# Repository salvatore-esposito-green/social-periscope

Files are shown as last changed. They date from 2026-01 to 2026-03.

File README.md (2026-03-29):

🛰️ ESP32 Social Periscope (Radar Badge)
========================================

### 🔗 Project Context & Evolution

This experiment is based on the **[Codemotion Smart Badge](https://github.com/Codemotion-Official/CMNode)**. It was born from the idea of hacking and developing custom add-ons for the **CMNode V0** version.

While the original project was designed for **passive operation** (displaying check-in data), this "Social Periscope" version evolves the hardware into an **active device** capable of real-time peer-to-peer detection and interaction.

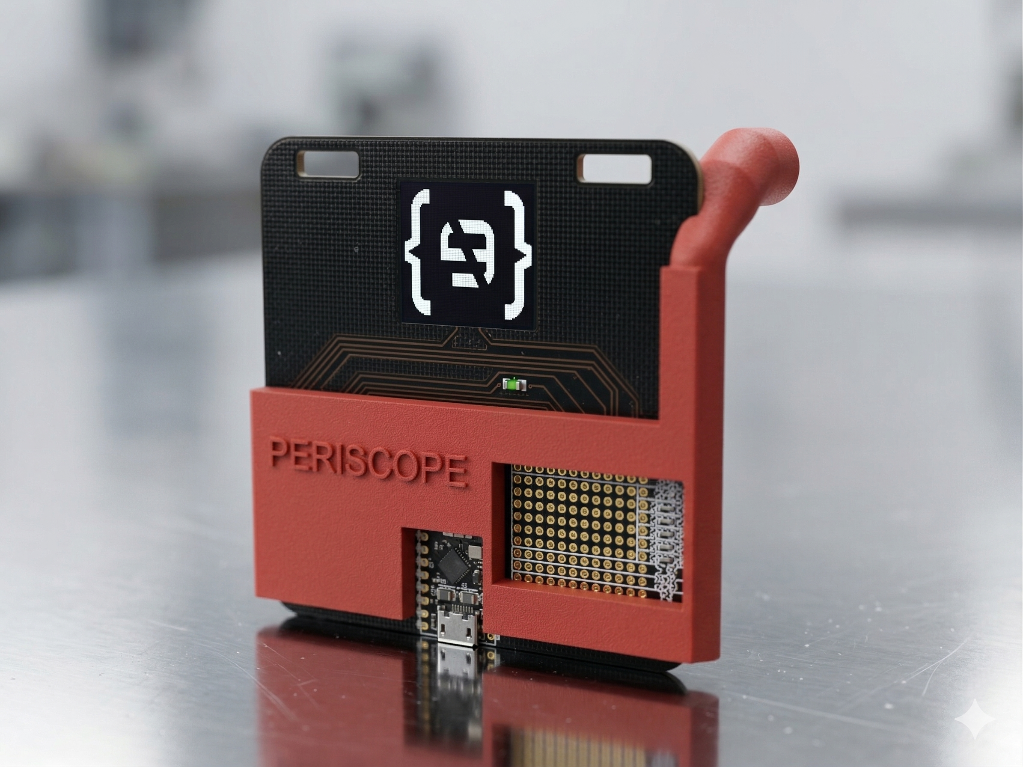
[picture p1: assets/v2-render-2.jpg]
Codemotion Badge Original


## Overview: The "Active" Evolution

This firmware transforms the static badge into an interactive **Social Radar**. It uses **ESP-NOW** and **RSSI (Signal Strength)** monitoring to detect other nearby badges, automatically swapping contact information when you get close to another attendee.

Badge Demo
📹 **[Watch full demo video on YouTube](https://youtu.be/3y3iBChB-LI)**

### Key Logic Overview

1.  **Broadcast**: Every 300ms, the device sends its own profile data to any nearby device.
2.  **Detection (Proximity Alert)**: It calculates a "Smooth RSSI" (signal strength). As a peer gets closer, the buzzer beeps faster and at a higher pitch (Geiger-counter style).
3.  **Target Acquisition**: If a peer is very close (RSSI > -80), it triggers a 5-second alarm and then updates the E-Paper display with the "Target's" information and QR code.

### 🚀 How It Works

1.  **Broadcast Mode**: The device constantly broadcasts your profile (Name, Role, Company, and QR Link) via **ESP-NOW** (no Wi-Fi router required).
2.  **Proximity Sensing**: It monitors the **RSSI** (Signal Strength) of nearby devices.
3.  **Geiger-Style Alerts**: As you get closer to another user, the buzzer beeps faster and at a higher pitch.
4.  **Target Acquisition**: If someone stays within immediate range (approx. 1-2 meters) for a few seconds, the device "locks on," triggers an alarm, and updates the E-Paper display with the other person's details and QR code.

### 🛠 Hardware Configuration

This version assumes the following components are added to the base CMNode V0:

*   **Microcontroller**: ESP32 (e.g., ESP32-S3 or C3)
*   **Display**: GxEPD2 compatible 2.9" 3-Color E-Paper Display
*   **Audio**: Active/Passive Buzzer (connected to Pin 3)
*   **Visual**: Status LED (connected to Pin 8)
*   **Communication**: ESP-NOW (2.4GHz)

### 🏗️ Physical Build & Assembly

#### v2 — Improved Design

> An updated version of the enclosure with a revised CAD model, optimized for better component fit and aesthetics.

<table>
  <tr>
    <td width="50%">
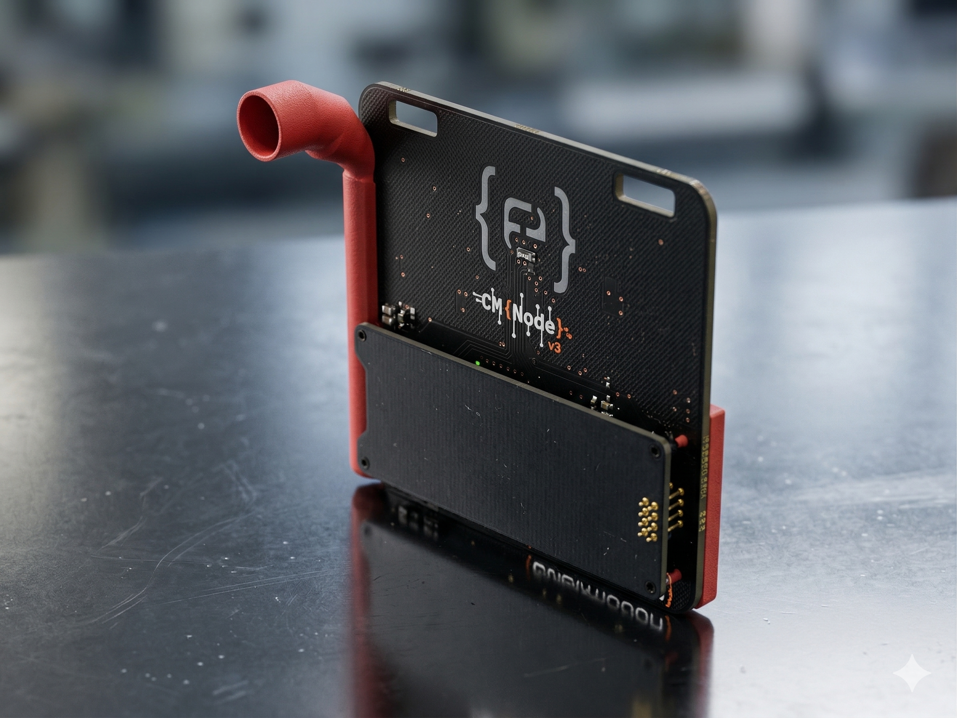
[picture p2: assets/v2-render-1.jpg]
v2 Render 1
      
      <p align="center"><em>Photorealistic render — front</em></p>
    </td>
    <td width="50%">
      v2 Render 2
      <p align="center"><em>Photorealistic render — back</em></p>
    </td>
  </tr>
</table>

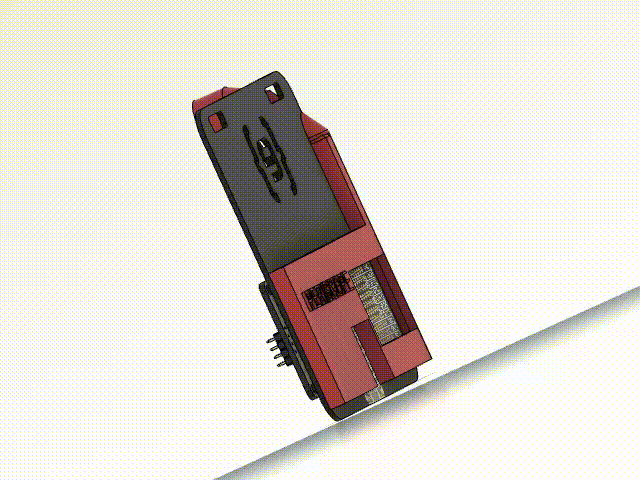
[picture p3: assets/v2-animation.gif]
v2 3D Animation


<table>
  <tr>
    <td width="50%">
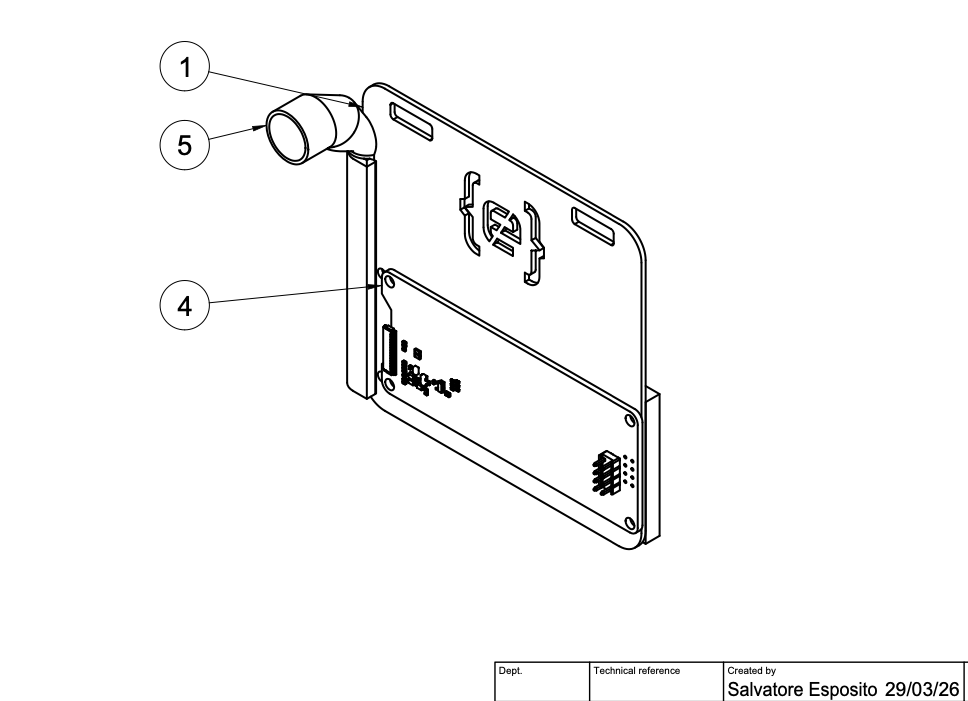
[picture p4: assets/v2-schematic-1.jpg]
Design schematic 1
      
      <p align="center"><em>Design schematic — sheet 1</em></p>
    </td>
    <td width="50%">
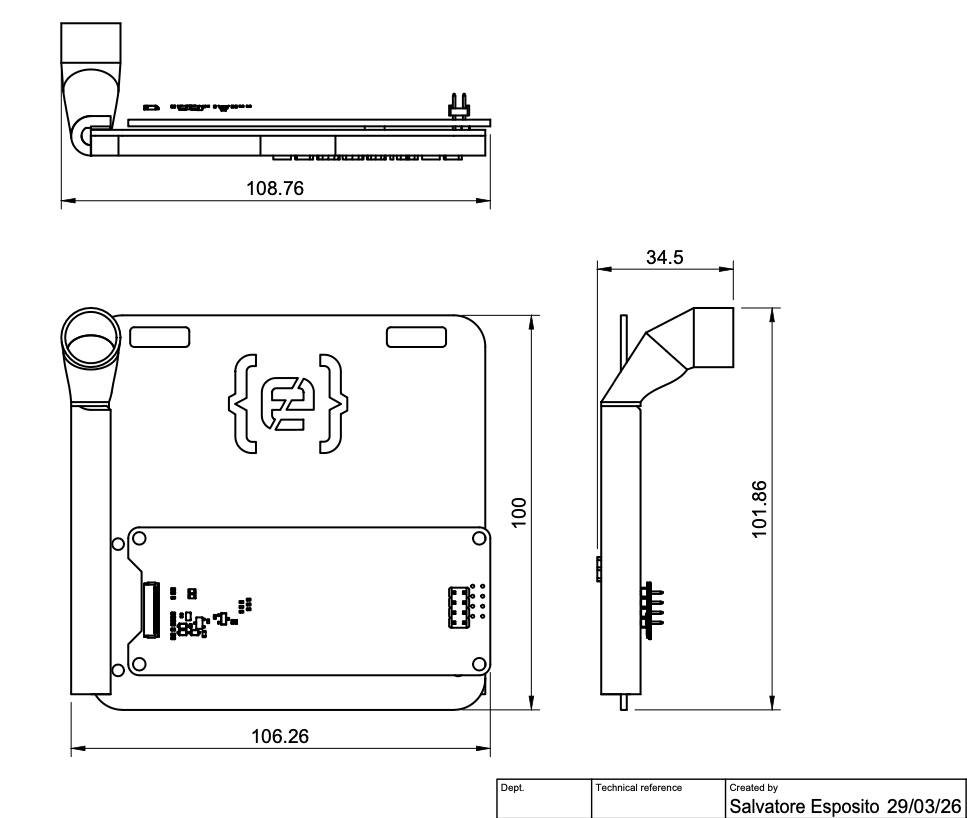
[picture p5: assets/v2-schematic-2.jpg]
Design schematic 2
      
      <p align="center"><em>Design schematic — sheet 2</em></p>
    </td>
  </tr>
</table>

<table>
  <tr>
    <td width="50%">
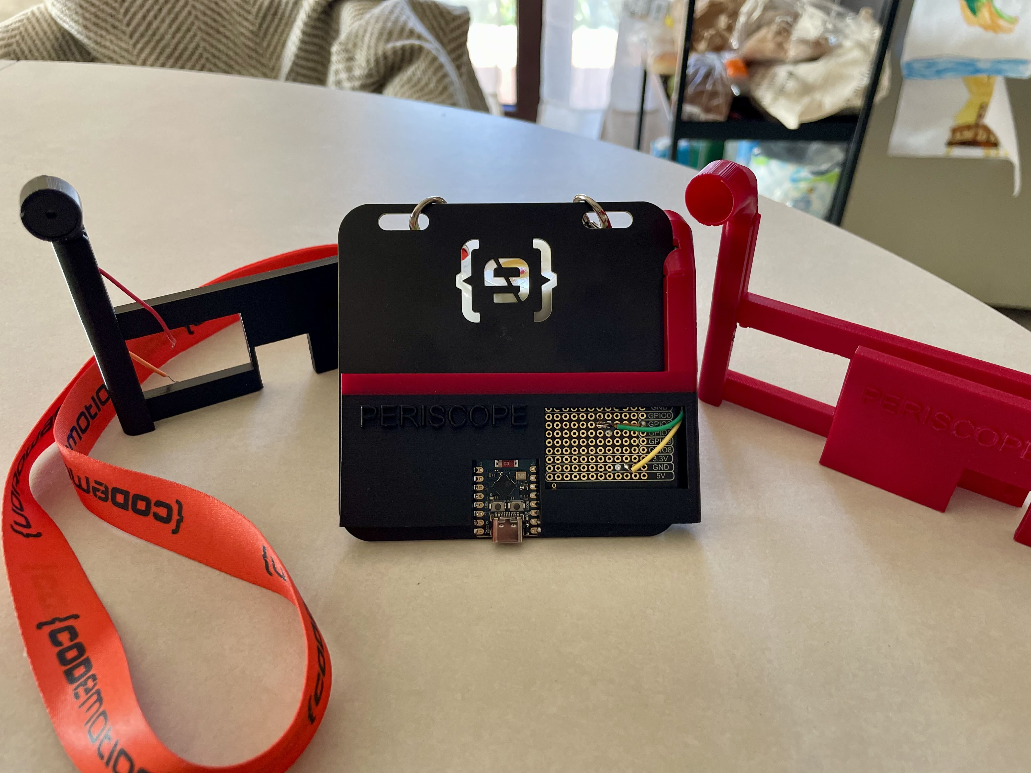
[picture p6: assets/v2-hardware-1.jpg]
v2 hardware on table 1
      
      <p align="center"><em>Badge and supports — table view</em></p>
    </td>
    <td width="50%">
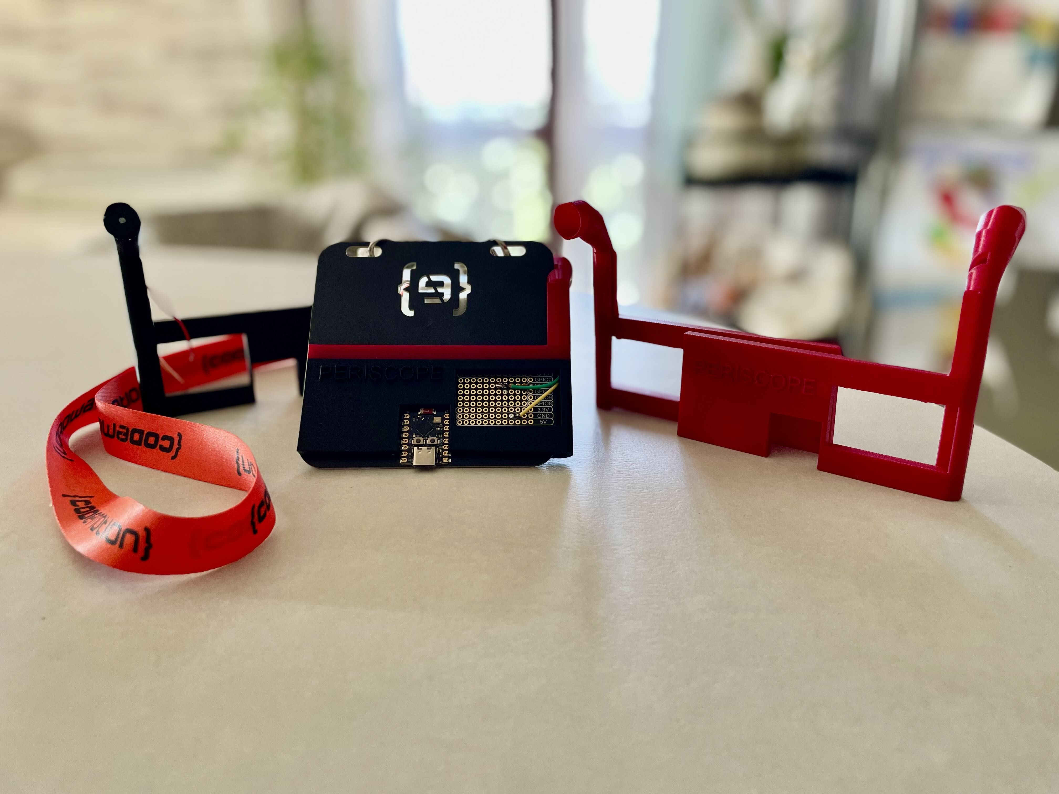
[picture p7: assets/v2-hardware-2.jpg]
v2 hardware on table 2
      
      <p align="center"><em>Badge and supports — table view</em></p>
    </td>
  </tr>
</table>

📦 **[Download STL file](assets/social-periscope-v2.stl)**

---

#### v1 — Original Build

> The first physical iteration, built and tested at the Codemotion event.

<table>
  <tr>
    <td width="50%">
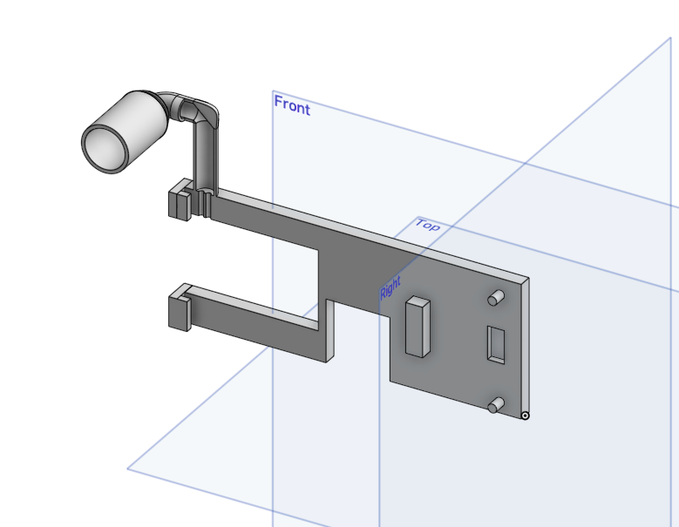
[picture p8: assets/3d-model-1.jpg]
      
      <p align="center"><em>3D modeling of the periscope</em></p>
    </td>
    <td width="50%">
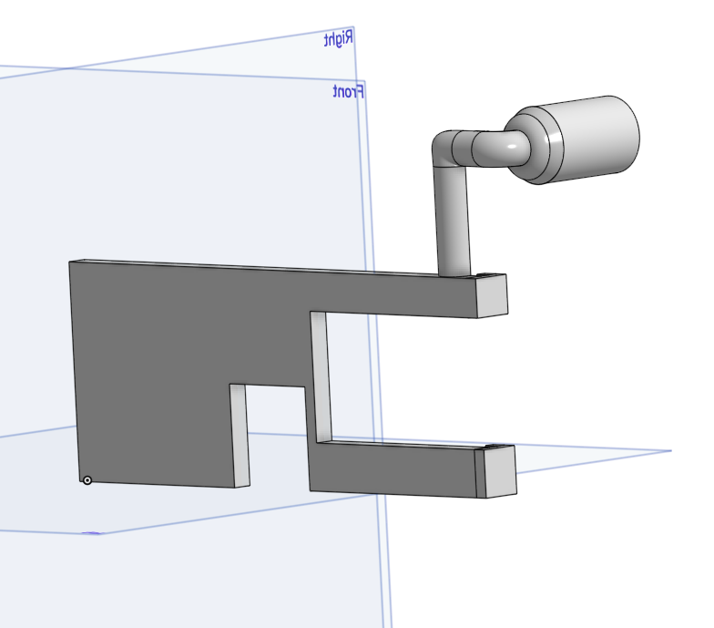
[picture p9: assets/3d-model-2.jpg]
      
      <p align="center"><em>3D modeling of the periscope</em></p>
    </td>
  </tr>
    <tr>
    <td width="50%">
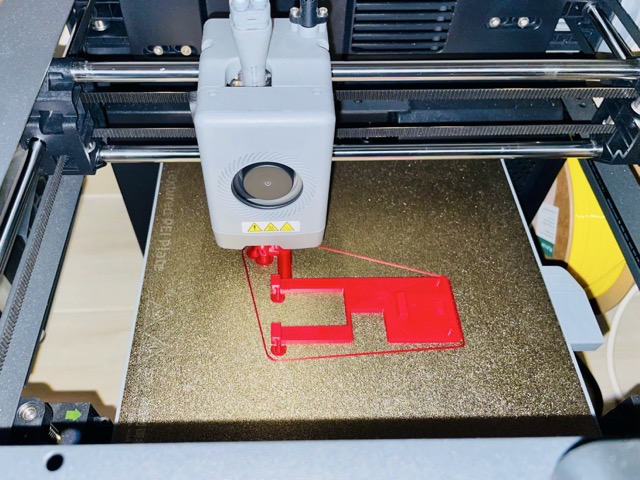
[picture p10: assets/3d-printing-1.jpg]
3D Printing in Progress
      
      <p align="center"><em>3D printing of the case</em></p>
    </td>
    <td width="50%">
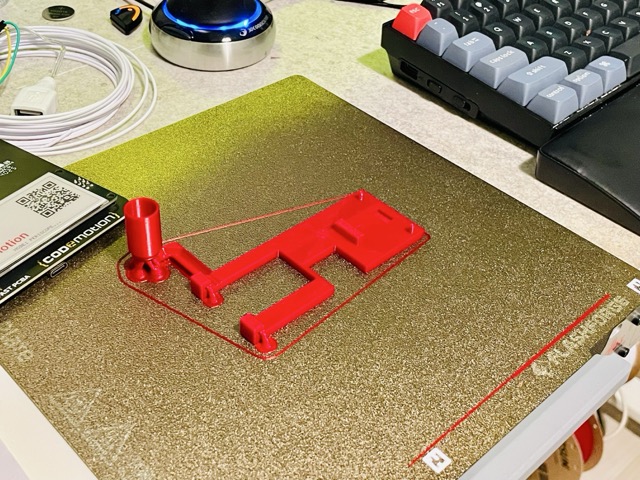
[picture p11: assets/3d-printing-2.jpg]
3D Printing in Progress
      
      <p align="center"><em>3D printing of the case</em></p>
    </td>
  </tr>
  <tr>
    <td width="50%">
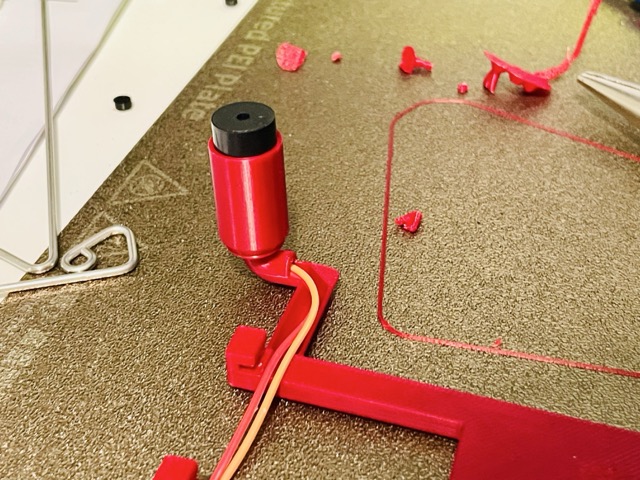
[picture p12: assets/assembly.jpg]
Buzzer Wiring
      
      <p align="center"><em>Buzzer wiring</em></p>
    </td>
    <td width="50%">
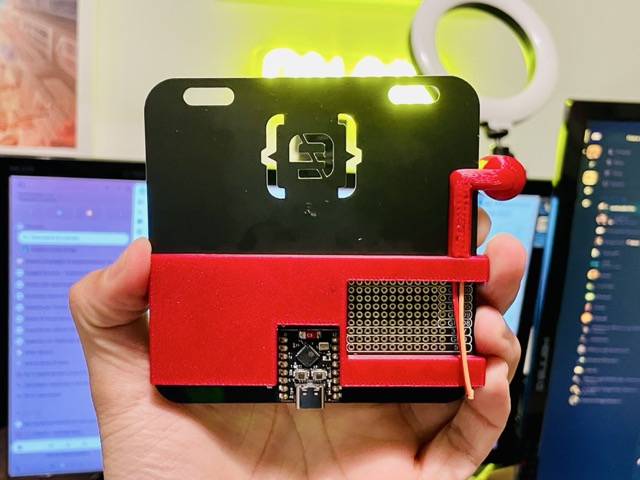
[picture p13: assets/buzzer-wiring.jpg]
Component Assembly
      
      <p align="center"><em>Assembly</em></p>
    </td>
  </tr>
  <tr>
    <td width="50%">
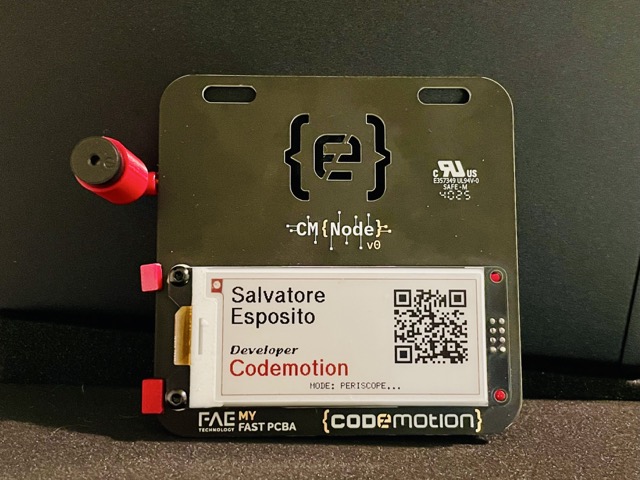
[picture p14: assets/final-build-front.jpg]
Fully Assembled Badge Front
      
      <p align="center"><em>Fully assembled badge</em></p>
    </td>
    <td width="50%">
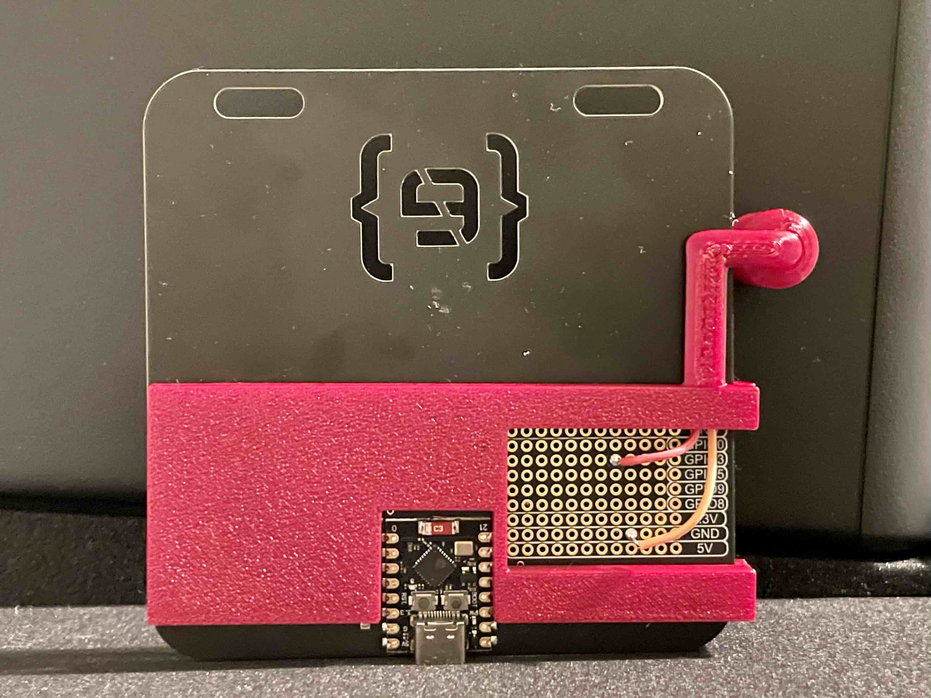
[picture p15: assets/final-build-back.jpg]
Fully Assembled Badge Back
      
      <p align="center"><em>Fully assembled badge</em></p>
    </td>
  </tr>
</table>

### 📂 Project Structure

*   **ESP-NOW Logic**: Peer-to-peer data exchange without latency.
*   **EMA Filtering**: Smooths RSSI fluctuations to prevent false "Target Acquired" triggers.
*   **Display Management**: Full refresh cycles using `GxEPD2`, featuring hibernation to preserve the E-Ink panel.
*   **Audio PWM**: Dynamic pitch mapping (800Hz to 3500Hz) based on proximity.

### 🔧 Installation & Setup

1.  **Clone the repository**:

```bash
git clone https://github.com/salvatore-esposito-green/social-periscope.git
```

2.  **Configure your Profile**: Edit the `myProfile` struct in the code:

```C++
struct_message myProfile = {"Name", "Surname", "Role", "Company", "URL"};
```

3.  **Library Dependencies**:

*   `GxEPD2`
*   `U8g2_for_Adafruit_GFX`
*   `QRCodeGFX`

4.  **Upload**: Flash to your ESP32-C3 using the Arduino IDE or PlatformIO.

### 📟 Device States

| Mode | Description | Audio/Visual Feedback |
| :--- | :--- | :--- |
| **Idle (Periscope)** | No peers detected in range. | Silent. LED is OFF. Displays **Your** profile. |
| **Detection** | Peer detected nearby (-95 to -81 dBm). | "Geiger" clicks: faster and higher pitch as the person gets closer. |
| **Locked On** | Peer within immediate range (> -80 dBm). | 5-second continuous alarm. Display updates to show **Remote User's** info. |
| **Timeout** | Peer moves away for > 2.5s. | System resets. Display returns to **Your** profile. |

### 🤝 Credits & Acknowledgments

*   **Original Project**: [Codemotion Official Smart Badge](https://github.com/Codemotion-Official/CMNode)
*   **Concept**: Hacking the CMNode V0 to explore social interactions at tech conferences.

### ⚠️ Important Notes

*   **E-Ink Refresh**: E-Paper displays take ~2-5 seconds to refresh. During this time, the device UI will be unresponsive.
*   **Power Consumption**: The device uses high-power Wi-Fi transmission for maximum range. Consider using a LiPo battery with at least 500mAh.
*   **Safety**: Ensure the buzzer frequency (up to 3500Hz) is comfortable for your environment.

### 🤝 Contributing

Feel free to fork this project, report issues, or submit pull requests to improve the proximity algorithm or add new UI layouts!

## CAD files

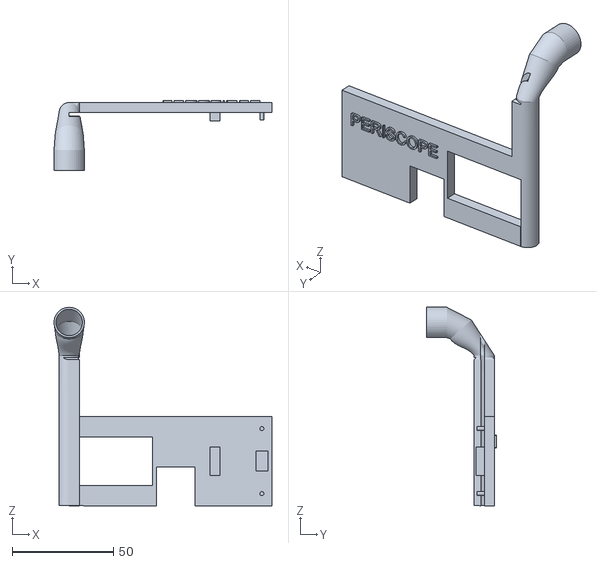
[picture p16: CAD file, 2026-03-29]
assets/social-periscope-v2.stl
107.5 x 34.5 x 97.9

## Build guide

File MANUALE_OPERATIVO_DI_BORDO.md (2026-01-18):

# 📟 SONAR BADGE: Codemotion Submarine Edition
_Protocollo di Aggancio Sociale tramite ESP-NOW_

Il **Sonar Badge** è un dispositivo di proximity-networking progettato per trasformare i corridoi di Codemotion in un oceano digitale. Dimentica il classico networking: qui siamo in modalità "**Battaglia Navale Collaborativa**".

## 🚀 La Tecnologia

A differenza del comune Bluetooth, il badge utilizza il protocollo **ESP-NOW** a 2.4GHz.

- **Zero Latenza**: Nessun accoppiamento richiesto. I sottomarini (badge) comunicano istantaneamente.

- **Rilevamento Passivo**: Il badge emette un "Ping" radio ogni 300ms.

- **Analisi RSSI**: Il sistema analizza la potenza del segnale ricevuto per calcolare la distanza dei sottomarini amici.

## 📡 Modalità PERISCOPIO (Sonar On)

Quando il tuo badge rileva un segnale radio amico, si attiva l'interfaccia acustica **Sonar**:

1. **Fase di Avvicinamento (Range 5m - 2m)**: Il buzzer emette un beep lento e profondo. È il primo contatto radar.

2. **Fase di Intercettazione (Range 2m - 1m)**: Il ritmo accelera progressivamente e il tono diventa più acuto. La tensione sale.

3. **Punto di Collisione (Sotto 1 metro)**: Il Sonar "impazzisce". Il ritmo raggiunge l'apice (50ms) e il suono diventa frenetico. **È il segnale: il sottomarino amico è di fronte a te!**

## 💬 Missione: "Quattro Chiacchiere"

Il Sonar Badge non serve a distruggere, ma a connettere. Una volta raggiunto l'apice del suono, il protocollo di bordo impone di:

- Emergere in superficie.

- Disattivare il sonar.

- Iniziare una conversazione reale con il "comandante" dell'altro badge.

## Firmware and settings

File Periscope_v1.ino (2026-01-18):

#include <Arduino.h>
#include <WiFi.h>
#include <esp_now.h>
#include <esp_wifi.h>
#include <GxEPD2_3C.h>
#include <U8g2_for_Adafruit_GFX.h>
#include <QRCodeGFX.h>

// --- HARDWARE CONFIGURATION ---
#define BUZZER_PIN 3
#define LED_PIN    8
#define WIFI_CHANNEL 1 

// E-Paper Display Pins (SPI)
#define EPD_CS      7
#define EPD_DC      1
#define EPD_RST     2
#define EPD_BUSY    10

// --- DATA STRUCTURES ---
typedef struct struct_message {
    char name[20];
    char surname[20];
    char role[20];
    char company[20];
    char qrLink[50];
} struct_message;

struct_message myProfile = {"Salvatore", "Esposito", "Developer", "Codemotion", "https://github.com/salvatore-esposito-green"};
struct_message receivedProfile;
struct_message myData;

// --- DISPLAY & GRAPHICS OBJECTS ---
GxEPD2_3C<GxEPD2_290_C90c, GxEPD2_290_C90c::HEIGHT> display(GxEPD2_290_C90c(EPD_CS, EPD_DC, EPD_RST, EPD_BUSY));
U8G2_FOR_ADAFRUIT_GFX u8g2;
QRCodeGFX qrcode(display);

// --- GLOBAL STATE VARIABLES ---
bool needRefresh = true;    // Triggers E-ink update
bool inContact = false;     // True if a peer is "locked on"
float smoothRSSI = -100.0;  // Filtered signal strength to prevent jitter
unsigned long lastRecvTime = 0;
unsigned long lastBeepTime = 0;
unsigned long lastSendTime = 0;
unsigned long beepOffTime = 0;
uint8_t broadcastAddr[] = {0xFF, 0xFF, 0xFF, 0xFF, 0xFF, 0xFF};

// --- AUDIO/VISUAL FEEDBACK ---
void startBeep(int freq) {
    ledcWriteTone(BUZZER_PIN, freq);
    digitalWrite(LED_PIN, LOW); // LED ON (assuming Active Low)
}

void stopBeep() {
    ledcWriteTone(BUZZER_PIN, 0);
    digitalWrite(LED_PIN, HIGH); // LED OFF
}

// --- GRAPHICS DRAWING FUNCTIONS ---

// Default screen showing my own info
void drawMyProfile() {
    u8g2.setBackgroundColor(GxEPD_WHITE);
    u8g2.setForegroundColor(GxEPD_BLACK);
    u8g2.setFont(u8g2_font_helvB18_tf);
    u8g2.setCursor(5, 25); u8g2.print(myProfile.name);
    u8g2.setCursor(5, 50); u8g2.print(myProfile.surname);
    
    u8g2.setFont(u8g2_font_luBIS10_tf);
    u8g2.setCursor(5, 85); u8g2.print(myProfile.role);
    
    u8g2.setForegroundColor(GxEPD_RED);
    u8g2.setFont(u8g2_font_helvB18_tf);
    u8g2.setCursor(5, 110); u8g2.print(myProfile.company);
    
    qrcode.generateData(myProfile.qrLink);
    qrcode.setScale(3);
    qrcode.draw(display.width() - qrcode.getSideLength(), 0);
    
    u8g2.setForegroundColor(GxEPD_BLACK);
    u8g2.setFont(u8g2_font_6x10_tf);
    u8g2.setCursor(100, 125); u8g2.print("MODE: PERISCOPE...");
}

// Screen shown when a nearby peer is detected
void drawTargetAcquired() {
    u8g2.setBackgroundColor(GxEPD_WHITE);
    u8g2.setForegroundColor(GxEPD_BLACK);
    u8g2.setFont(u8g2_font_6x12_tf);
    u8g2.setCursor(70, 15); u8g2.print("!!! TARGET ACQUIRED !!!");
    
    display.drawRect(0, 20, display.width(), 2, GxEPD_BLACK);
    
    u8g2.setFont(u8g2_font_helvB14_tf);
    u8g2.setCursor(10, 50); u8g2.print(receivedProfile.name);
    u8g2.setCursor(10, 70); u8g2.print(receivedProfile.surname);
    
    u8g2.setFont(u8g2_font_6x12_tf);
    u8g2.setCursor(10, 95); u8g2.print(receivedProfile.role);
    
    u8g2.setForegroundColor(GxEPD_RED);
    u8g2.setCursor(10, 110); u8g2.print(receivedProfile.company);
    
    qrcode.generateData(receivedProfile.qrLink);
    qrcode.setScale(3);
    int qrSize = qrcode.getSideLength();
    qrcode.draw(display.width() - qrSize - 5, display.height() - qrSize - 5);
}

void drawContent() {
    if (inContact) drawTargetAcquired();
    else drawMyProfile();
}

// Full refresh handler for E-Ink (Slow process)
void refreshDisplay() {
    display.init(115200, true, 50, false);
    display.setRotation(3);
    display.setFullWindow();
    display.firstPage();
    do {
        display.fillScreen(GxEPD_WHITE);
        drawContent();
    } while (display.nextPage());
    display.hibernate(); // Put display to sleep to save power/prevent damage
    needRefresh = false;
}

// --- ESP-NOW CALLBACK ---
void OnDataRecv(const esp_now_recv_info_t *recv_info, const uint8_t *data, int len) {
    lastRecvTime = millis();
    if (recv_info->rx_ctrl != nullptr) {
        int currentRSSI = recv_info->rx_ctrl->rssi;
        // EMA Filter: 70% old value, 30% new value to smooth out signal spikes
        if (smoothRSSI < -99) smoothRSSI = currentRSSI;
        else smoothRSSI = (smoothRSSI * 0.7) + (currentRSSI * 0.3);
        
        memcpy(&receivedProfile, data, sizeof(receivedProfile));
    }
}

void setup() {
    Serial.begin(115200);
    
    // PWM Setup for Buzzer
    ledcAttach(BUZZER_PIN, 2000, 8);
    pinMode(LED_PIN, OUTPUT);
    digitalWrite(LED_PIN, HIGH);

    // WiFi & ESP-NOW Setup
    WiFi.mode(WIFI_STA);
    esp_wifi_start();
    esp_wifi_set_max_tx_power(78); // Max power for range
    esp_wifi_set_channel(WIFI_CHANNEL, WIFI_SECOND_CHAN_NONE);
    esp_now_init();
    esp_now_register_recv_cb(esp_now_recv_cb_t(OnDataRecv));
    
    // Register Broadcast Peer
    esp_now_peer_info_t peerInfo = {};
    memcpy(peerInfo.peer_addr, broadcastAddr, 6);
    peerInfo.channel = 0;
    esp_now_add_peer(&peerInfo);
    
    memcpy(&myData, &myProfile, sizeof(myData));

    // Display Init
    display.init(115200, true, 50, false);
    u8g2.begin(display);
    refreshDisplay();
    
    // Startup Sound
    startBeep(2000); delay(300); stopBeep();
}

void loop() {
    unsigned long now = millis();

    // Handle asynchronous buzzer shutoff
    if (now >= beepOffTime) stopBeep();

    // Broadcast my data every 300ms
    if (now - lastSendTime >= 300) {
        lastSendTime = now;
        esp_now_send(NULL, (uint8_t *) &myData, sizeof(myData));
    }

    // Timeout: If no data received for 2.5s, person has walked away
    if (now - lastRecvTime > 2500) {
        smoothRSSI = -100;
        if (inContact) { 
            inContact = false; 
            needRefresh = true; 
        }
    }

    int currentRSSI = (int)smoothRSSI;

    // RADAR LOGIC
    if (currentRSSI > -95) { // Potential target detected
        // Map RSSI to beep frequency (Distance logic)
        int clampedRSSI = constrain(currentRSSI, -95, -80);
        int interval = map(clampedRSSI, -95, -80, 2000, 50); // Faster beeps when closer

        if (now - lastBeepTime >= interval) {
            lastBeepTime = now;
            int pitch = map(clampedRSSI, -95, -80, 800, 3500); // Higher pitch when closer
            startBeep(pitch);
            beepOffTime = now + 20; // Short 20ms click/beep
        }

        // LOCK ON LOGIC: Target is very close
        if (currentRSSI > -80 && !inContact) {
            inContact = true;
            
            // Audible Alarm Phase (5 seconds)
            unsigned long waitStart = millis();
            while(millis() - waitStart < 5000) {
                if (millis() - lastBeepTime >= 50) {
                    lastBeepTime = millis();
                    startBeep(3500);
                    delay(15);
                    stopBeep();
                }
                yield(); // Prevent watchdog triggers
            }
            needRefresh = true; 
        }
    }

    // Execute E-Ink refresh if state changed
    if (needRefresh) {
        refreshDisplay();
        if (inContact) {
            // Once a target is captured, pause for 10s to let the user read/scan
            delay(10000); 
            lastBeepTime = millis();
            lastRecvTime = millis();
        }
    }
    yield();
}

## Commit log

2026-01-18 Add initial implementation of ESP32 Social Periscope with hardware configuration, display logic, and proximity detection features; include supporting assets and documentation.
2026-03-29 doc: Add v2 subsection with photorealistic renders, animation, schematics, hardware photos and STL download link
    [social-periscope-v2.stl]
